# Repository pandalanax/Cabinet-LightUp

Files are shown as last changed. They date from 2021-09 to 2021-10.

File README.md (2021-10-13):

# Cabinet-LightUp

photo of circuit

## Components
- WS2812 Strip with 30 LEDs
- Reed Switch
- Arduino Nano 
- MCP1700 LDO 
- 2N3904 Transistor
- 1N4007 Diode
- 100NF Cap
- 2x 1µF Cap
- 1k Ohm Resistor
- 3x AA Battery
- 1 Battery Case

## Arduino Nano Modifications
After Modification, the usage of the USB port of the Nano could damage it. I program the Nano via ICSP Pins with 3.3v.

#### Core
The Core was changed to [Minicore](https://github.com/MCUdude/MiniCore). Underclocked the Nano to 8Mhz using internal oscillator. 
#### LED
Removed the Resistor for the POWER led.
#### Voltage Regulator
The nanos voltage regulator uses a lot of energy, therefore i removed the regulator and changed it to a LDO MCP1700

## Circuit
Using the transistor alone didn't help to completely shut down the WS2812 strip. Found this helpful [thread](https://forum.pjrc.com/threads/24407-Strange-WS2812-NeoPixel-backfeed-current-FYIO) which suggested using a diode to eliminate the backfeeding problem through DATA channel.

## Current Draw Measurement
The current is measured with an external Arduino Nano and INA219 Breakout Board.
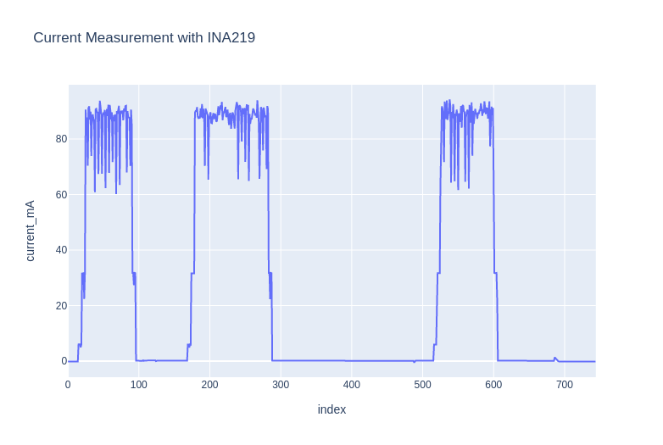
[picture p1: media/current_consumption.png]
photo of current draw


# TODO

- [x] add schematic
- [x] create pcb
- [ ] upload hex file to flash via avrdude 
- [ ] upload minicore settings to flash via avrdude

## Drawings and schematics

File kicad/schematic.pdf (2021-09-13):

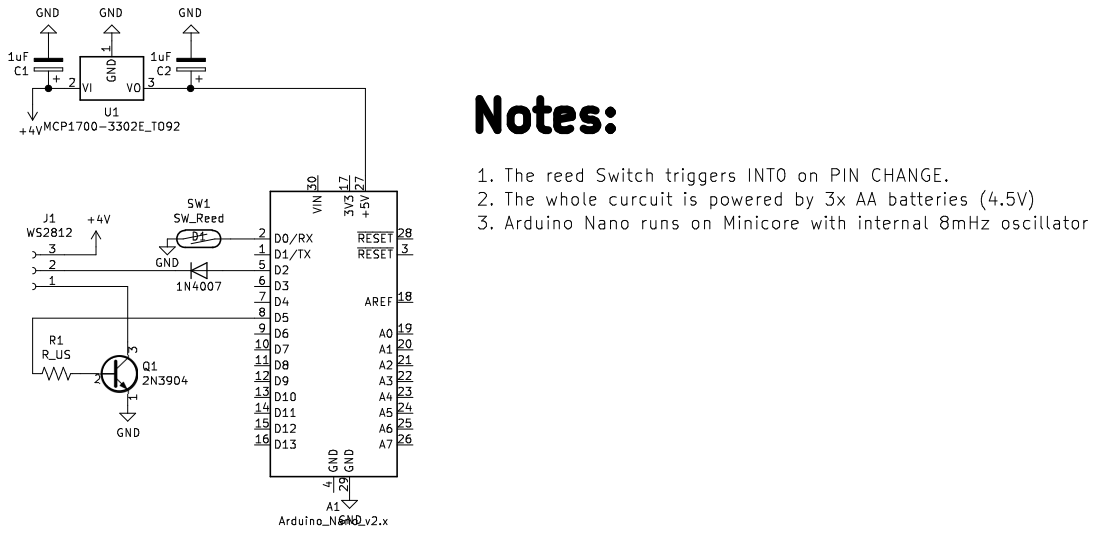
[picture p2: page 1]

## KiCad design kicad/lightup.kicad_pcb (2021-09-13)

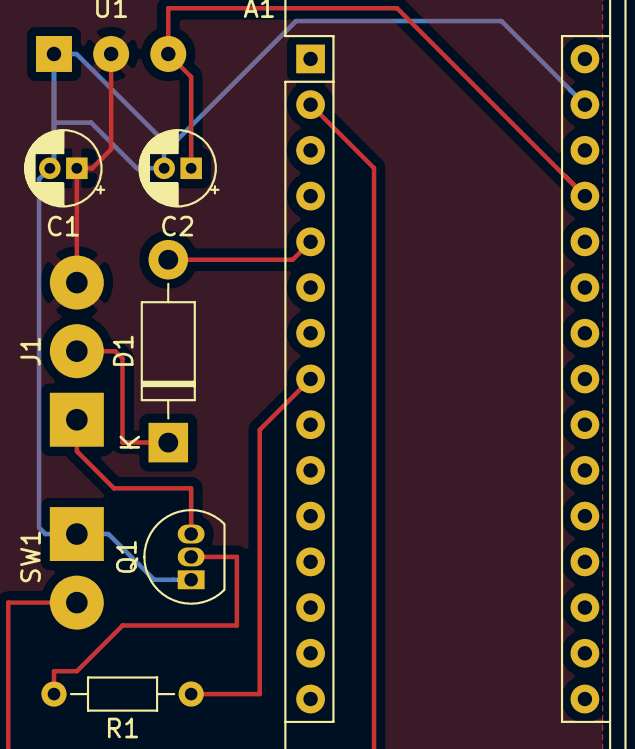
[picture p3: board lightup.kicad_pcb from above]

Board: 2 copper layers, 9 parts (0 on the bottom side), 9 nets.

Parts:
A1: Arduino_Nano_v2.x; Arduino_Nano
C1, C2: 1uF; CP_Radial_D4.0mm_P1.50mm
D1: 1N4007; D_DO-41_SOD81_P10.16mm_Horizontal
J1: WS2812; SolderWirePad_1x03_P3.81mm_Drill1.2mm
Q1: 2N3904; TO-92_Inline
R1: R_US; R_Axial_DIN0204_L3.6mm_D1.6mm_P7.62mm_Horizontal
SW1: SW_Reed; SolderWirePad_1x02_P3.81mm_Drill1.2mm
U1: MCP1700-3302E_TO92; SolderWirePad_1x03_P3.175mm_Drill0.8mm

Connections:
+4V: C1.1, J1.3, U1.2
GND: A1.29, C1.2, C2.2, Q1.1, SW1.1, U1.1
unnamed: A1.2, SW1.2
unnamed: A1.5, D1.2
unnamed: A1.8, R1.1
unnamed: A1.27, C2.1, U1.3
unnamed: D1.1, J1.2
unnamed: J1.1, Q1.3
unnamed: Q1.2, R1.2

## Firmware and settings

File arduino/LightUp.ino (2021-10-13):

#include <FastLED.h>
#include <avr/sleep.h>//this AVR library contains the methods
#define REED_PIN    0// Pin connected to reed switch
#define LED_PIN     2
#define SWITCH_PIN  5
#define NUM_LEDS    30
#define BRIGHTNESS  64
#define LED_TYPE    WS2811
#define COLOR_ORDER GRB

CRGB leds[NUM_LEDS];

#define UPDATES_PER_SECOND 100

volatile bool awake = true;

void reed(){
  sleep_disable();//Disable sleep mode
  awake = digitalRead(REED_PIN);   // read the input pin;
}


void rainbow_march(uint8_t thisdelay, uint8_t deltahue) {     // The fill_rainbow call doesn't support brightness levels.

  uint8_t thishue = millis()*(255-thisdelay)/255;             // To change the rate, add a beat or something to the result. 'thisdelay' must be a fixed value.
  
// thishue = beat8(50);                                       // This uses a FastLED sawtooth generator. Again, the '50' should not change on the fly.
// thishue = beatsin8(50,0,255);                              // This can change speeds on the fly. You can also add these to each other.
  
  fill_rainbow(leds, NUM_LEDS, thishue, deltahue);            // Use FastLED's fill_rainbow routine.

}
  
void setup() 
{
  // Since the other end of the reed switch is connected to ground, we need
  // to pull-up the reed switch pin internally.
  pinMode(REED_PIN, INPUT_PULLUP);
  pinMode(SWITCH_PIN, OUTPUT);

  FastLED.addLeds<LED_TYPE, LED_PIN, COLOR_ORDER>(leds, NUM_LEDS).setCorrection( TypicalLEDStrip );
  FastLED.setBrightness(  BRIGHTNESS );

  attachInterrupt(0, reed, CHANGE);//attaching a interrupt to pin d2
  ADCSRA = 0;  
}

void loop(){
  //Serial.println(awake);
  if(awake){
    digitalWrite(SWITCH_PIN, HIGH);
    delay(500);
    rainbow_march(200, 10);
    FastLED.show();
  }else{
    

    sleep_enable();//Enabling sleep mode
    set_sleep_mode(SLEEP_MODE_PWR_DOWN);//Setting the sleep mode, in our case full sleep

    FastLED.clear();
    FastLED.show();
    delay(1000); //wait a second to allow the led to be turned off before going to sleep
    digitalWrite(SWITCH_PIN,LOW);
    sleep_cpu();//activating sleep mode
  }
}

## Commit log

2021-09-13 added kicad files
    [lightup.kicad_pcb, lightup.sch]
2021-10-13 got confused with pins - fixed
    [LightUp.ino]
